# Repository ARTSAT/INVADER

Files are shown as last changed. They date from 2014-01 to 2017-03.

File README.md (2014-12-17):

Hardware / Software design of ARTSAT1:INVADER
========
This repository is for hardware / software design of ARTSAT1:INVADER.  

o satellite/body : contains INVADER's body design and CAD data.  
o satellite/power : contains power OBC's CAD data and source codes.  
o satellite/main : contains main OBC's CAD data and source codes.  
o satellite/mission : contains mission OBC's CAD data and source codes.  
o ground_station/mission : contains some utility software for mission operation.  
o ground_station/utility : contains some utility software such as a viewer or an editor, etc...

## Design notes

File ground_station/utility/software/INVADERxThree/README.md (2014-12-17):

INVADERxThree
=============

A library to handle ARTSAT1:INVADER as the 3D object in Three.js

```html
<script src="three.min.js"></script>
<script src="STLLoader.js"></script>
<script src="invaderxthree.js"></script>

<script>
  ..... // initialization for three.js (renderer, scene, camera, light, etc.)
  
  var invader = new Invader (scene); // INVADER is added to the scene!
  
  ..... // process for the animation
  
</script>
```

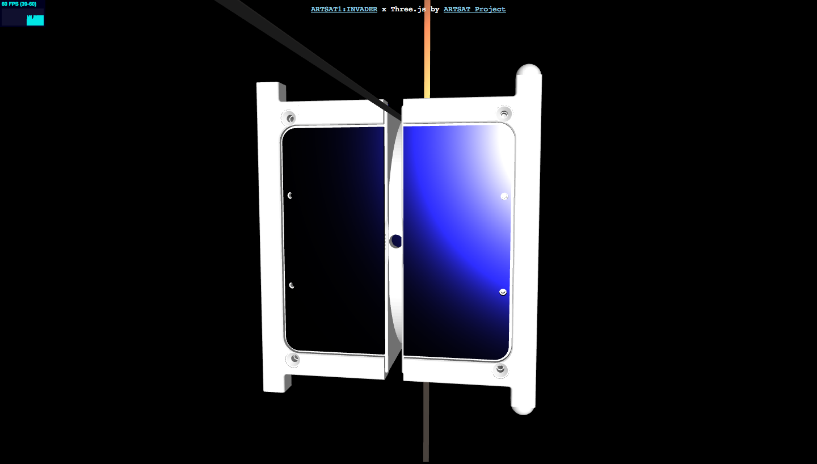
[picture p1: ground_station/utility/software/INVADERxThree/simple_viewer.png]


Demo: http://mokk.net/invaderxthree/examples/spinning.html

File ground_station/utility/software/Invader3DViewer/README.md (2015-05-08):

Invader3DViewer
====
A 3D viewer for INVADER, writted in Javascript.

## Description

[INVADER](http://artsat.jp/en/project/invader), a nano-satellite developed by ARTSAT project, can be viewed on your browser. 
You can zoom in/out and rotate the satellite.

## Demo

http://mokk.net/invader3d/

## Screen shot

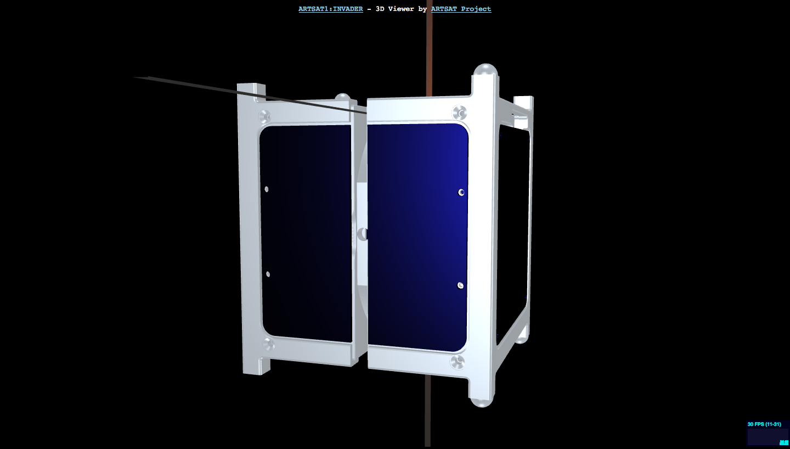
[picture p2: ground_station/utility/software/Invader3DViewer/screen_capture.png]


## Requirement

A browser that supports WebGL (Google Chrome is recommended).

## Licence

This software is released under the MIT License, see LICENSE.txt.

## Author

[Motoki Kimura](https://github.com/motokimura)

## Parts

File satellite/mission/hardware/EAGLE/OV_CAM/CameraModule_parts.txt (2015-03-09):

カメラモジュール部品情報

FFCケーブルの仕様
aitendo  http://www.aitendo.com/page/35

購入品
FFCケーブル(各種)　\480　http://www.aitendo.com/product/7256
　
16極　0.5mmピッチ　全長16cm　逆面導体露出タイプ　を指定

カメラモジュール

OV7670　(刻印がHDF 70-818)
　http://www.aitendo.com/product/2508

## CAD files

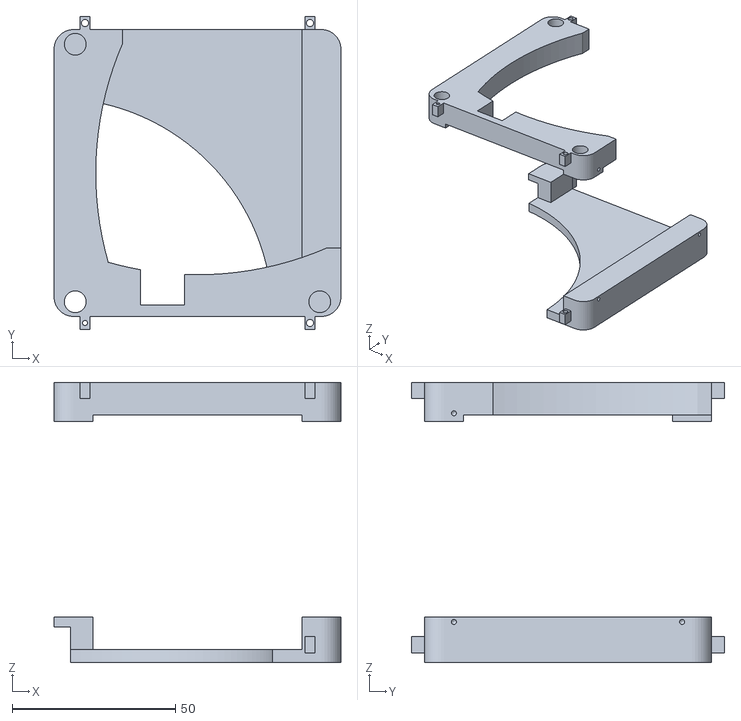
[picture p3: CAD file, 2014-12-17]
ground_station/utility/software/Invader3DViewer/models/invader_weights.stl
88.0 x 96.0 x 86.0

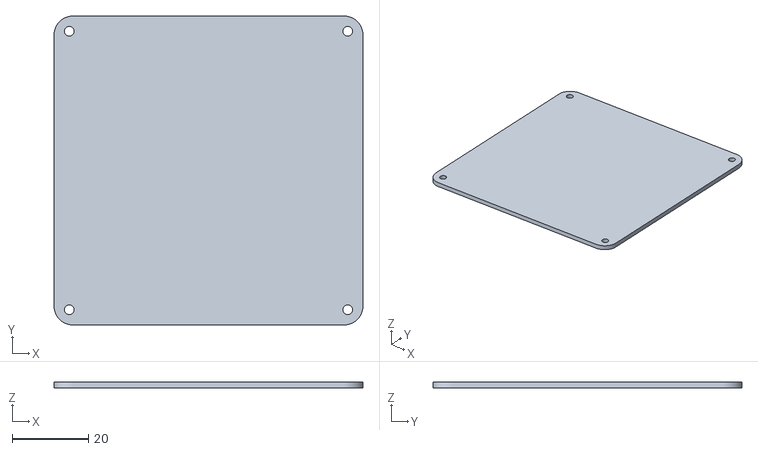
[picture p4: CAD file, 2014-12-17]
ground_station/utility/software/INVADERxThree/models/invader_pannel_mx.stl
81.0 x 81.0 x 1.60

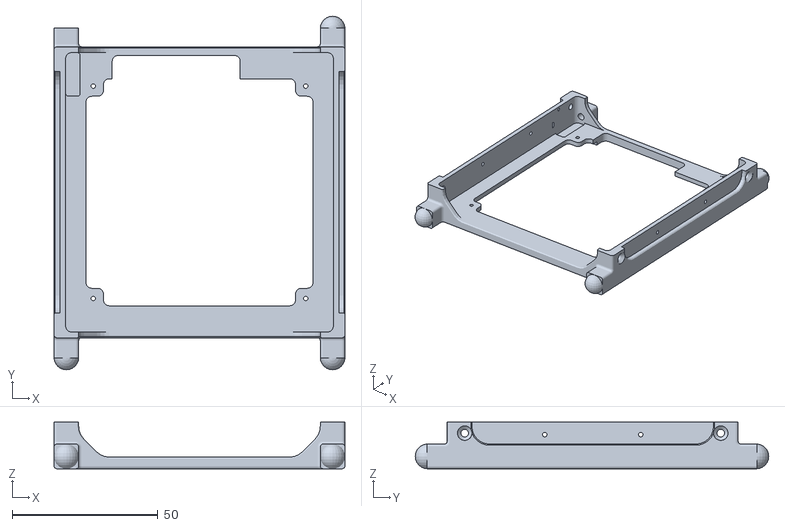
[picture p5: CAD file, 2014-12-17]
satellite/body/hardware/STL/+X.stl
100.0 x 121.5 x 16.0

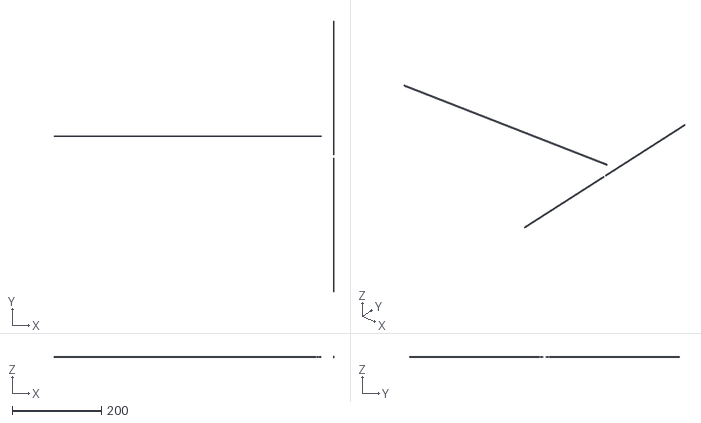
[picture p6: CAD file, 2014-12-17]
ground_station/utility/software/Invader3DViewer/models/invader_antennas.stl
629.0 x 606.8 x 3.00

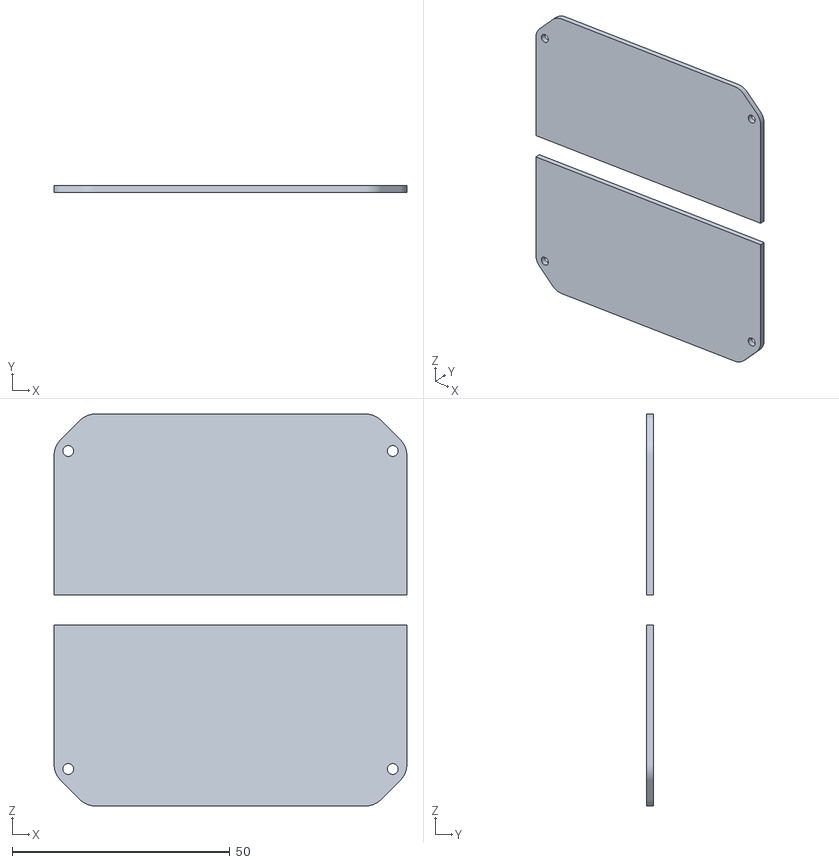
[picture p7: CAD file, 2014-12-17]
ground_station/utility/software/INVADERxThree/models/invader_pannel_mz.stl
81.0 x 1.60 x 90.0

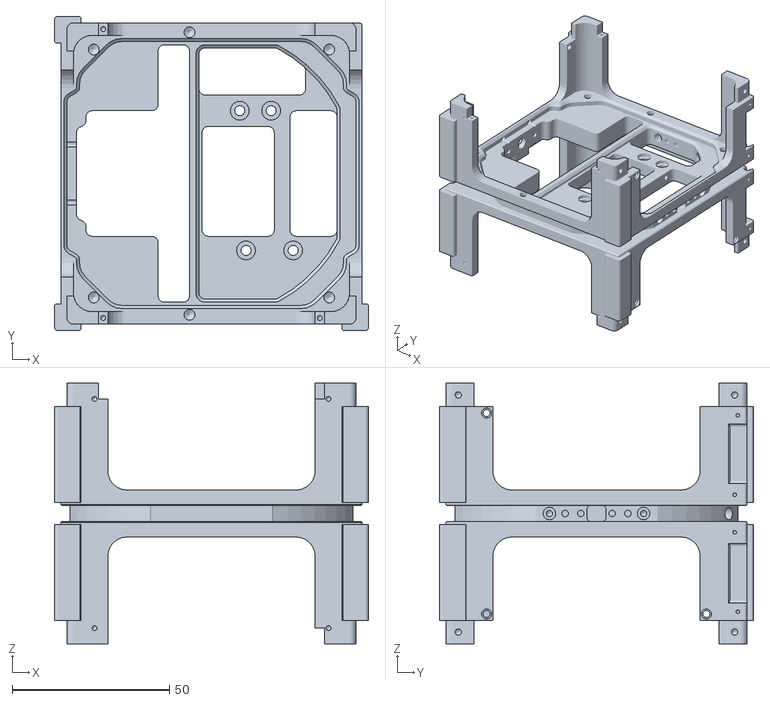
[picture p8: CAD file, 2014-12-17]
satellite/body/hardware/STL/body.stl
100.0 x 100.0 x 83.0

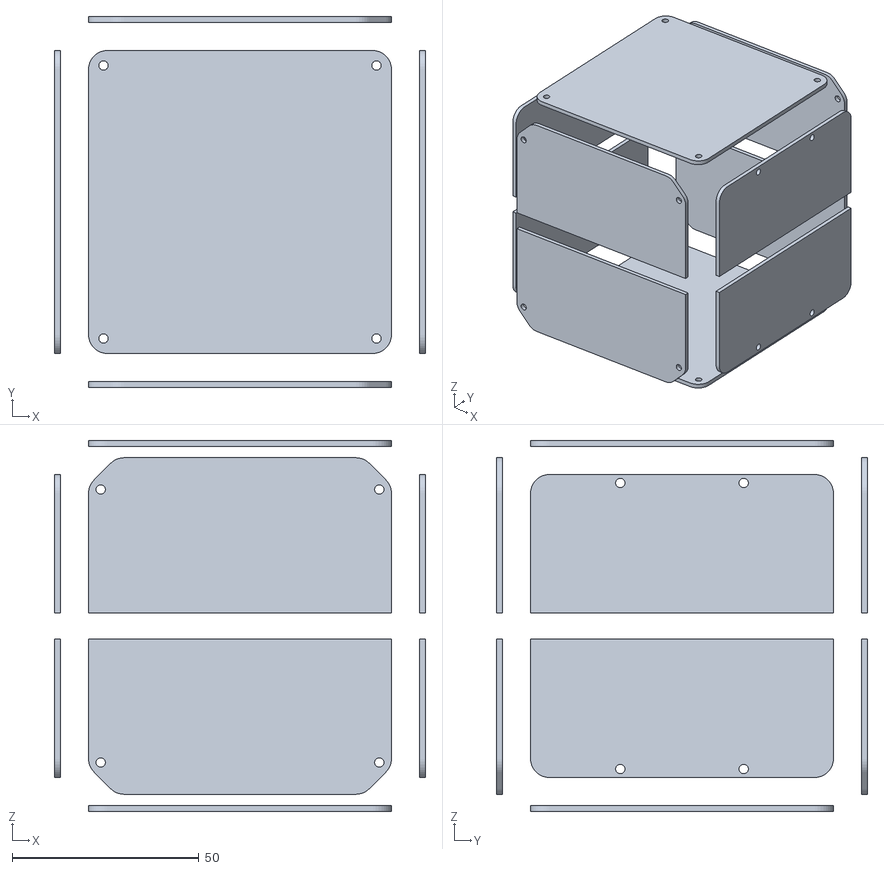
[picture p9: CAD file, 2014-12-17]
ground_station/utility/software/Invader3DViewer/models/invader_pannels.stl
99.2 x 99.2 x 99.2

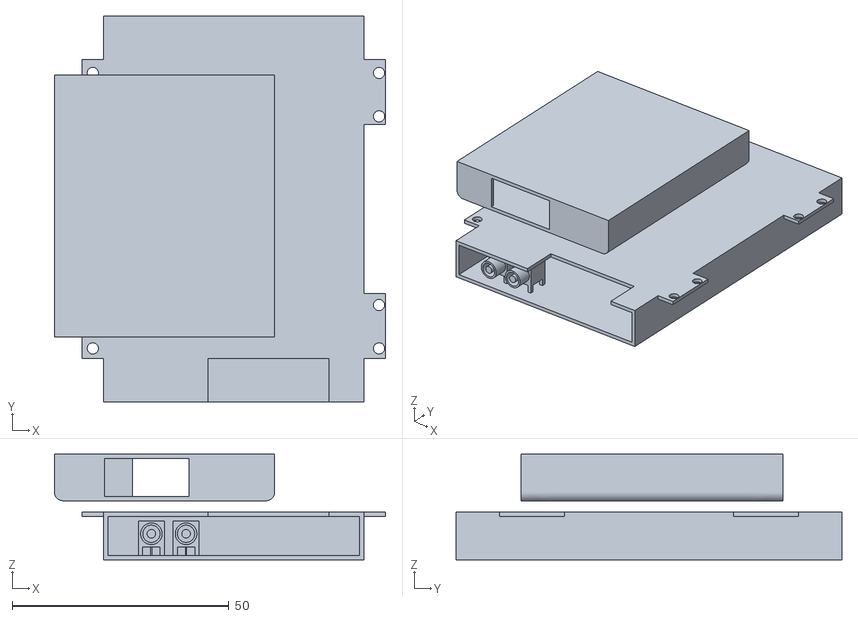
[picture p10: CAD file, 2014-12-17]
ground_station/utility/software/Invader3DViewer/models/invader_telecoms.stl
76.4 x 89.0 x 24.4

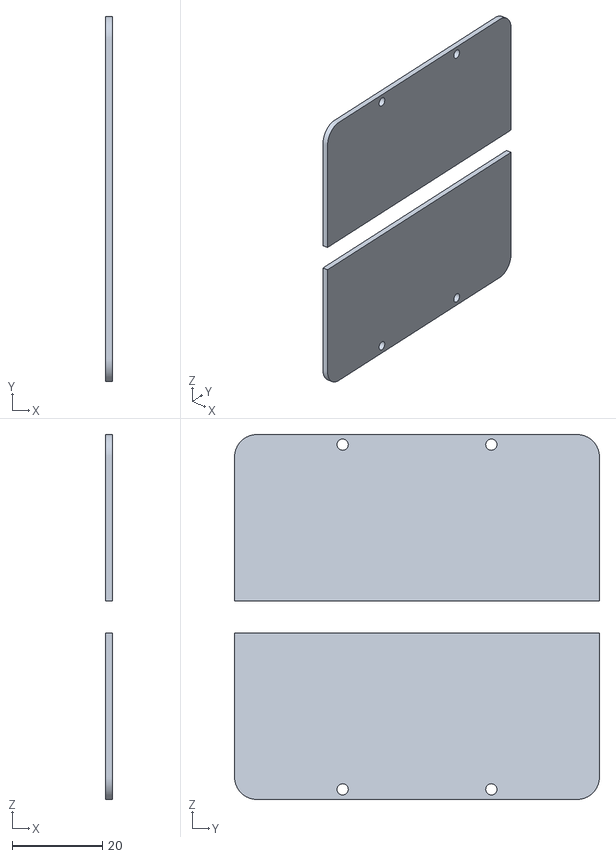
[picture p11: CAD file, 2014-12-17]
ground_station/utility/software/INVADERxThree/models/invader_pannel_my.stl
1.60 x 81.0 x 81.0

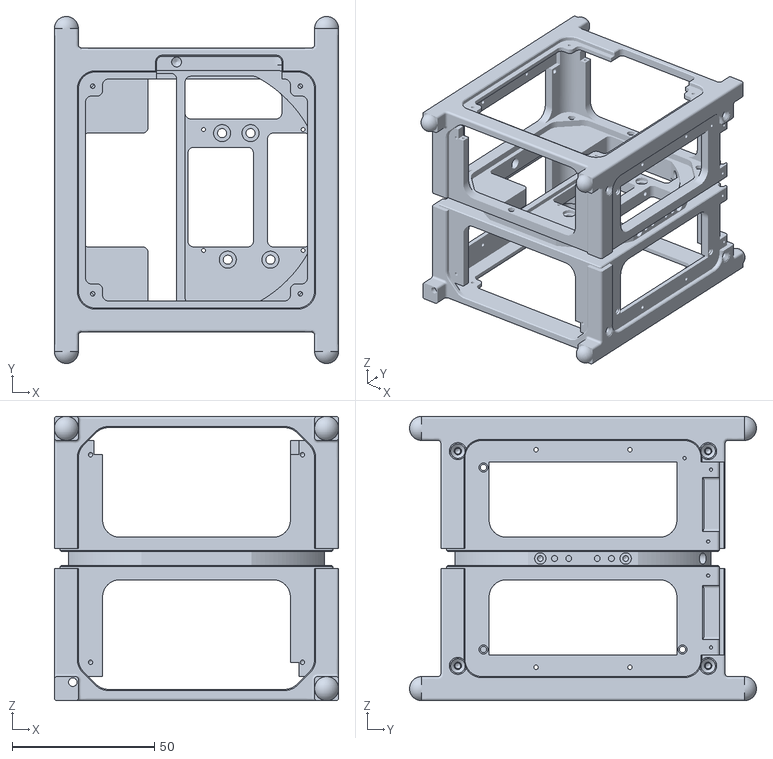
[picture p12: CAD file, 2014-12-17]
ground_station/utility/software/Invader3DViewer/models/invader_frame.stl
100.0 x 122.0 x 100.0

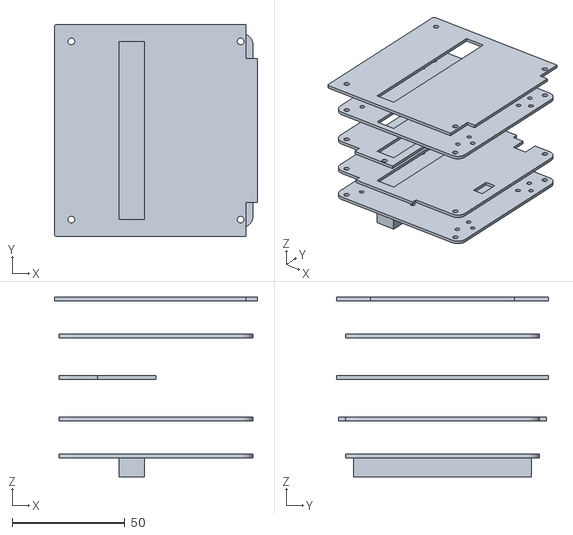
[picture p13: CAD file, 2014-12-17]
ground_station/utility/software/Invader3DViewer/models/invader_boards.stl
90.0 x 94.0 x 79.6

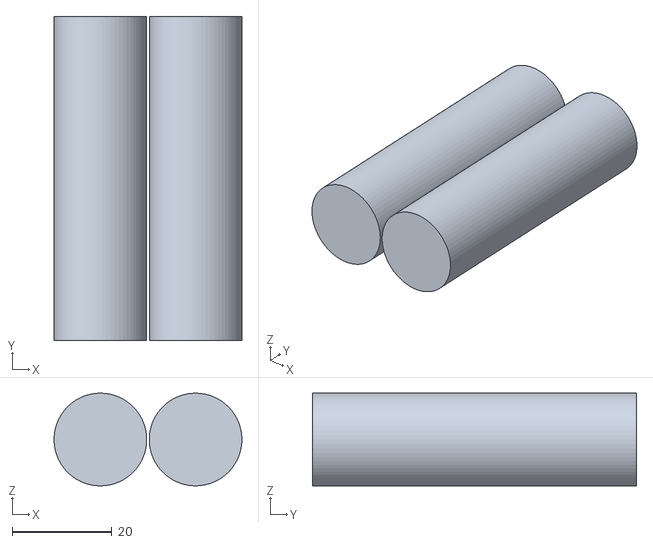
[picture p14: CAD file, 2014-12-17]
ground_station/utility/software/Invader3DViewer/models/invader_batteries.stl
37.7 x 65.0 x 18.6

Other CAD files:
ground_station/utility/software/INVADERxThree/models/invader_pannel_px.stl
ground_station/utility/software/INVADERxThree/models/invader_pannel_pz.stl
ground_station/utility/software/INVADERxThree/models/invader_pannel_py.stl
satellite/body/hardware/Inventor/FM_ver3_1/+X-ver3.12-1.idw
satellite/body/hardware/Inventor/FM_ver3_1/+X-ver3.12.ipt
satellite/body/hardware/Inventor/FM_ver3_1/-X-ver3.12.idw
satellite/body/hardware/Inventor/FM_ver3_1/-X-ver3.12.ipt
satellite/body/hardware/Inventor/FM_ver3_1/body_ver3.17.idw
satellite/body/hardware/Inventor/FM_ver3_1/body_ver3.17.ipt
satellite/body/hardware/STL/-X.stl

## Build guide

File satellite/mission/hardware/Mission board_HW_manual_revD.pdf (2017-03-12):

# ARTSAT Mission board Developer’s Manual

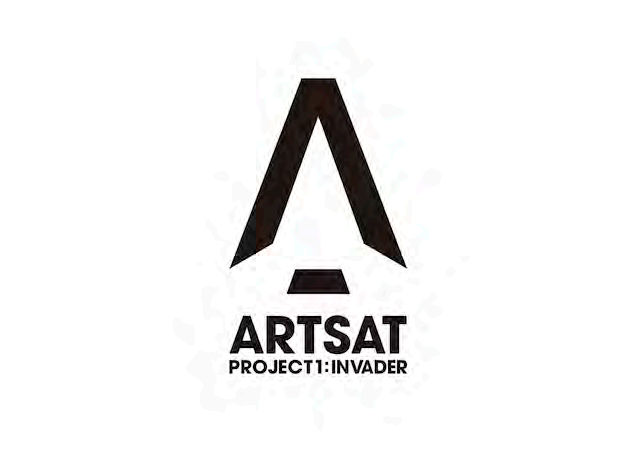
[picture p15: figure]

# Code name: MORIKAWA

# Flight Model

2017/03/12

## Kent Nakazawa (kent_n@outlook.com)

## ・INVADER 衛星(CO-77)の Arduino 互換ミッション機器

## ・Arduino IDE によるアプリケーション開発(MORIKAWA SDK)

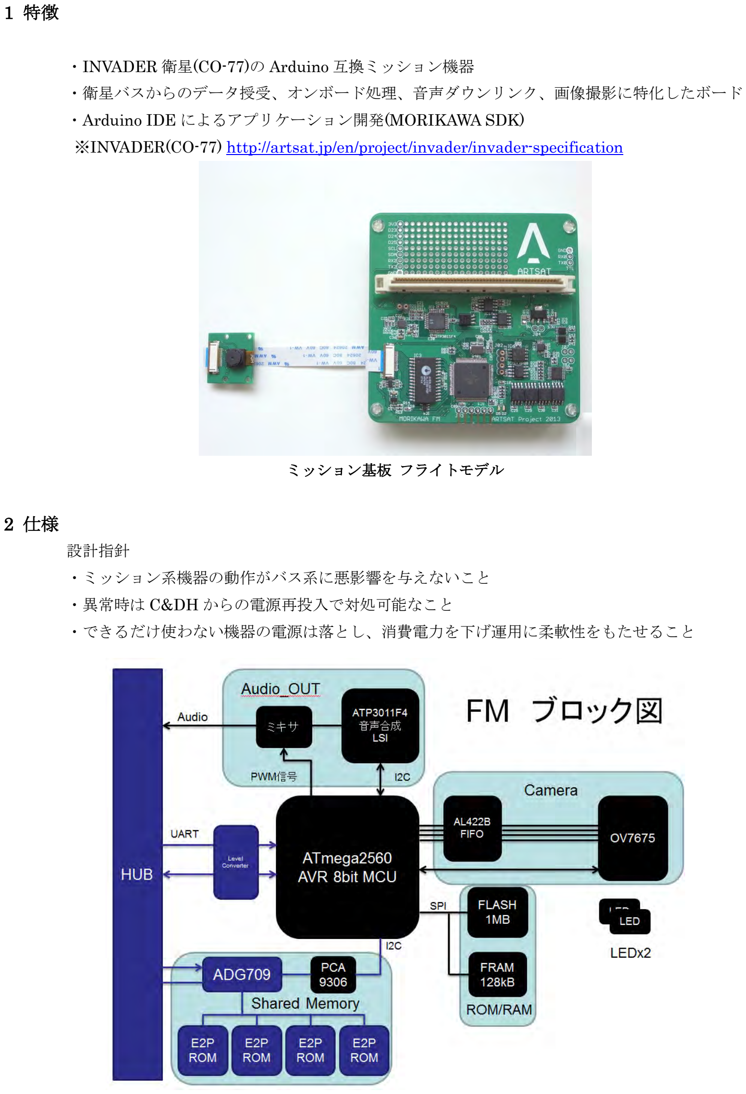
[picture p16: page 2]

1 特徴

・衛星バスからのデータ授受、オンボード処理、音声ダウンリンク、画像撮影に特化したボード

## ※INVADER(CO-77) http://artsat.jp/en/project/invader/invader-specification

ミッション基板 フライトモデル

2 仕様

設計指針
・ミッション系機器の動作がバス系に悪影響を与えないこと
・異常時は C&DH からの電源再投入で対処可能なこと

・できるだけ使わない機器の電源は落とし、消費電力を下げ運用に柔軟性をもたせること

## 2.1 MCU ・ATmega2560(RAM8kB,ROM256kB) 動作周波数 8MHz タイプ

・同期/非同期シリアル I2C_1ch, SPI_1ch,UART_4ch,
2.2 カメラモジュール
・OV7670 CMOS フライトモデルではレンズ一体型モジュールを使用。

## ・AL422B VGA FIFO ・12 / 24MHz クロック発振器 FM は 12MHzOSC

・ピン接続仕様は市販の FIFO 付きカメラモジュールと互換 ・カメラ用素子(モジュール、FIFO)の電源は未使用時に OFF

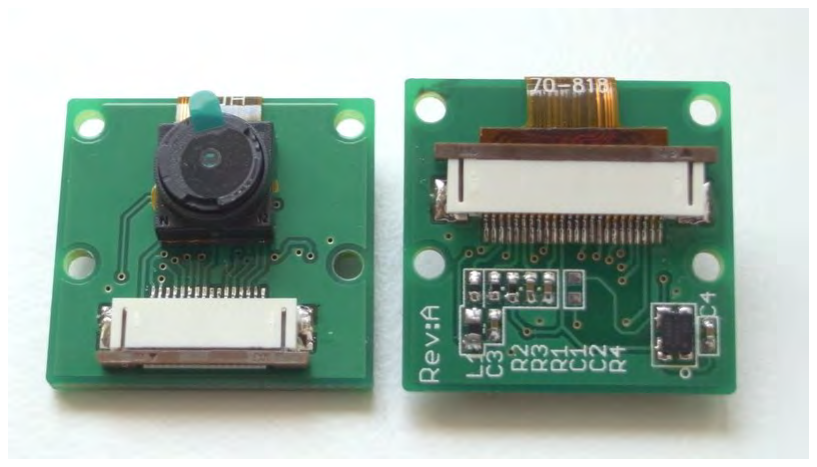
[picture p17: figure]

カメラモジュール 子基板

## 2.3 音声合成 LSI ATP3011F4 日本語音声合成 IC 通信: I2C

## 2.4 不揮発性 RAM ・SPI FRAM 128kB FM25V10

・消費電流が少なく、1 バイト単位でのアクセスが可能な不揮発性メモリ ・M25P80 とピン互換
・Flash や EEPROM へ保存する前のバッファメモリ等
2.5 大容量 ROM ストレージ

## ・SPI Flash メモリ 1MB M25P80

・Flash メモリ。画像、処理結果データの保存先として確保 2.8 共有メモリ

## ・EEPROM(24LC1025) x4 個 電源ドメインは 5V 系

・Main 系が、マルチプレクサ ADG709 によりアクセス権を設定 (LOW=バス系、HIGH=ミッション 系 切り替えラインはプルダウン) し、Mission 側に切り替え権は無い ・基板上のジャンパピンにより単独でアクセス可能 (開発用機能)

バス接続時、フライト時はジャンパピンを外すこと

## 2.6 LED x2 ・ATmega2560 へ接続(正論理)

・主にステータス確認用

2.7 INVADER バス接続用インターフェース

## ・バスは 5V 系 Mission は 3.3V 系

・共有メモリ、バス温度センサは 5V 系、C&DH 電源で動作 ・2 電源バスバッファにより電圧変換(UART、共有メモリ I2C)

3 開発環境

3.1 ソフトウェア開発環境

機器一覧

## ・USB-Serial 変換器/プログラマ https://www.sparkfun.com/products/9873

・リセット(DTR)がついた TTL レベル UART 接続 5V 供給できるもの

## ・PC/Mac/Linux ・既製品の Arduino ボード（ArduinoISP として使用）

・Arduino IDE(1.0.6) ※最新の IDE ではボード定義の追加が難しいため、1.0.6 での構築を推奨

## https://www.arduino.cc/en/Main/OldSoftwareReleases#previous

## 3.2 Arduino IDE 設定 (ArduinoIDE バージョン 1.0.6)

・Arduino IDE をインストールする
・MorikawaSDK に必要なファイルをダウンロードする。

## https://github.com/ARTSAT/MorikawaSDK をダウンロードし、 Arduino ディレクトリ内の二つのディレクトリ（libraries, hardware）を ArduinoIDE のスケッチ保存フォルダ（デフォルトでは documents/Arduino 内）に

入れる。
・ArduinoIDE を立ち上げ、ツール/board からボード選択リストを開き、

## Mega Pro 2560V 3.3V を選択

3.3 AVR ブートローダ設定

## ATmega2560 8MHz 版ブートローダの設定

・MORIKAWA にシリアルブートローダーを設定することで、シリアルポートからスケッチをアップロ

ードできる
・書き込みは ICSP という方式で、Arduino ボードをライターとして使用する手法を使う ・ICSP 用 4 ピン端子(J02 )を J02 に設けており、Arduino ISP 等で書き込みが可能

書き込みの流れは以下のサイトを参考にする

## https://www.arduino.cc/en/Tutorial/ArduinoISP Morikawa での各種端子の位置は、ピンアサイン表（MISSION_board_HW_layout.pdf）を参照

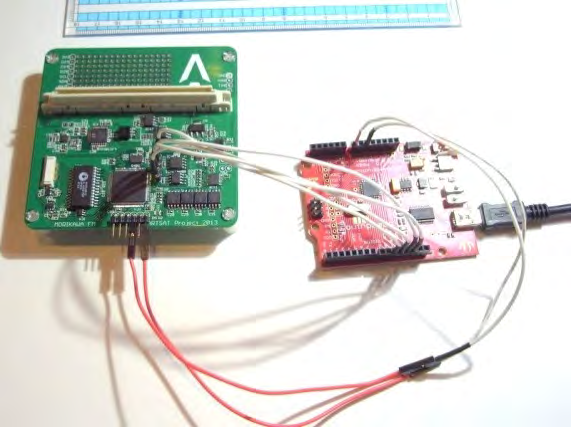
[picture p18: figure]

Arduino ISP によるブートローダーの書き込み

簡易手順
・まず、ライター用の Arduino ボードの設定で、スケッチ例から ArduinoISP を選択し、書き込む ・次に、ターゲットとなるボードの設定（mega-pro-3.3V）を選択する
・ライター用ボードの SPI 端子、リセット端子を、MORIKAWA ボードの J02 端子に接続する ・MORIKAWA への電源投入を行う。（5V 程度）
・IDE のツール/書き込み装置 にて、Arduino as ISP が選択されているか確認する ・ツール/ブートローダーを書き込む をクリックし、書き込みを行う

（結線や設定が間違っている場合、エラーが発生する）

## 3.4 Morikawa Software 書き込み、動作確認 Arduino IDE の設定 ボード設定: mega pro 2560V 3.3V

ポート：接続した USB シリアルポートの COM 番号

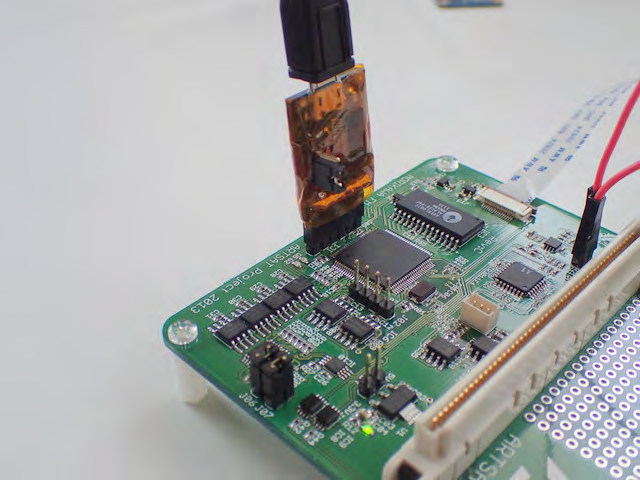
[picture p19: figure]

USB シリアル変換器の接続
・ファイル/スケッチの例から、MorikawaSDK を選択する。

・動作確認する場合は、

## DebugTest(ボードの動作確認)

HelloSpace(デジトーカーと音声のテスト)

を選択し、書き込んで単体で動作を確認できる
音声出力は、ジャンパ線をモノラルのオーディオジャックに接続すれば、ヘッドホンやスピ ーカーに直接繋いで確認できる。

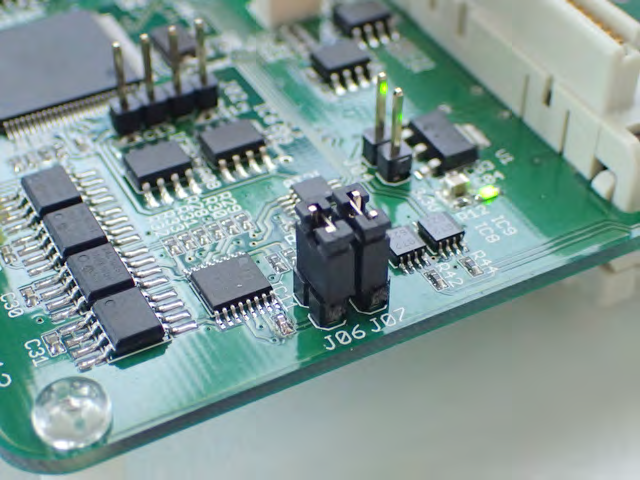
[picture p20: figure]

単体での動作確認の際は、I2C の共有メモリ部のジャンパピンを二つとも図のように接続する。

3.5 連携開発時の注意

・Invader 衛星に組み込んだ後は、USB シリアル変換器から電源を入力しないよう 6 ピン端子から電 源ピンを除去する。MORIKAWA の電源は Invader のシステムから投入
・ICSP 書き込みは 5V 系のボードからでも OK ・念のためその日の最初の電源投入前に、電源ライン（J04）がショートしていないか調べる ・I2C 機器をテストする場合、ボード単体では 2 つのジャンパピンをショートさせる必要がある （単体でオープン状態だと、音声合成 IC と共有メモリにアクセスできない） 逆に、Main と接続したり、連系試験を行う場合は、ジャンパピンを必ず取り除くこと

4 電気特性

・消費電流

## case1, 5V 系なし、周辺機器設定なし、UART 115k で 100ms ごとに送信: 9mA case2, カメラ系 ON 時: 約 60mA (数秒間)

5 設計情報

## Power Domain

基板上の回路は 3 つの電源ドメインから構成される

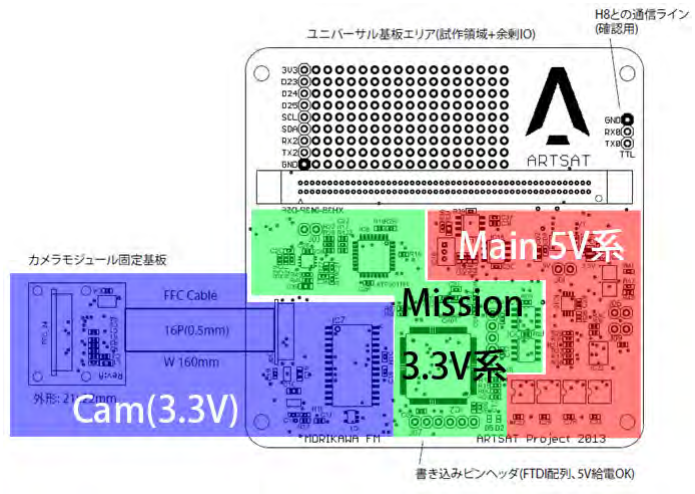
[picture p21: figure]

5V 系は Main 基板の延長となり、Main の電力(5V)をもらい常時通電している。
ミッションは 3.3V 系であり、Main の指令で、衛星の電源系により電源投入される

カメラ系はアプリによって、ミッション系から電源投入される。消費電力を下げるため、撮影終了とともにカメ ラモジュールの内部クロックを下限値まで落とし、FIFO の読み出し時の電力削減を行っている

※ユニバーサルエリアは試作部品追加が可能なように設けた すぐそばに電源ライン、AVR の UART 1ch,I2C バス、デジタル I/Ox3 を引き出した シルク印刷のピン番号は ArduinoAPI のピン番号となっている

## (参照 MISSION_FM_HW_layout)

FM 品の修正)

フライトモデルについて、搭載前の基板への変更点
・カメラ回路: VSYNC と WRST が繋がっていない 解決策: MCU 端子をハンダブリッジ(35,36 番ピン) ・回路修正: リセットライン ATMEGA2560 と ATP3011F4 間の接続を分離(パターンカット) ・回路修正: C01、R07、R43 は未実装
・回路図中の LED の極性が逆（そのまま実装すると光らない）

5 資料

## Artsat GitHub https://github.com/ARTSAT/MorikawaSDK

6 設計データリビジョン

・フライトモデル: Rev:A (基板上での修正)
・2015/03/24 | Rev:C (リワーク内容の反映、部品削除、部品定数の変更) Rev:A とソフトウェア互換あり
・2017 March | Rev:D (LED の極性の反映、書き込み手順の追加)

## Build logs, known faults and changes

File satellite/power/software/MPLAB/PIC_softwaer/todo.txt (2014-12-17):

プログラム改修
・CW間隔をコマンドで変更できるようにする
・CWの周波数を修正
・CWの間隔はあけてないかも知れない！！＜要確認
・前
・今、ヒータは動かないようにしている（閾値で）

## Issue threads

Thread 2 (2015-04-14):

ArtSat Project on STEMN

DaveRevay2, 2015-04-14:
Hey ArtSat team,

I've been collecting together a database of awesome satellite projects and posting them on [STEMN](https://stemn.com/fields/cubesat).

I've added your ArtSat projects already:
https://stemn.com/projects/invader-artsat-1
https://stemn.com/projects/despatch-artsat-2

It'd be really great if you could join the STEMN community. I'll transfer the project ownership over to you if you do. STEMN allows you to blog about your projects, contact other teams and ask questions in space related forums.

We’re currently in closed beta but you can sign up using the following link:
https://stemn.com/?org=J05312734
Once you’ve made an account, or if you have any questions, send me a email at david@stemn.com and I can transfer the project to your account.

Thanks, David

hemokosa, 2015-04-14:
Dear David,

Hello! Thank you very much for checking our ARTSAT project.
We are very glad that you added our two spacecrafts on your site.

I have signed in to  STEMN now. I will check it and mail you again.

Thanks again and keep in touch.

All the best,

Akihiro Kubota
Project Leader, ARTSAT Project

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

DaveRevay2, 2015-04-15:
Thanks for your quick reply Akihiro,

I'm very excited to have you on the platform. Now that I have transferred the project over to you, you can invite any other team members.
https://stemn.com/threads/%5Bhow-to%5D-how-do-i-add-new-team-members-to-my-project.

Should I invite you to the DESPATCH project also?

Kind regards and thanks, David

hemokosa, 2015-04-15:
Dear David,

Thanks. Please invite me to the DESPATCH project, too!

All the best,

Akihiro Kubota

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

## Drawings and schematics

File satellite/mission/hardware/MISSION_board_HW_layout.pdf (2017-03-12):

## MORIKAWA (FM) HardWare Pin Map 2017/03/12

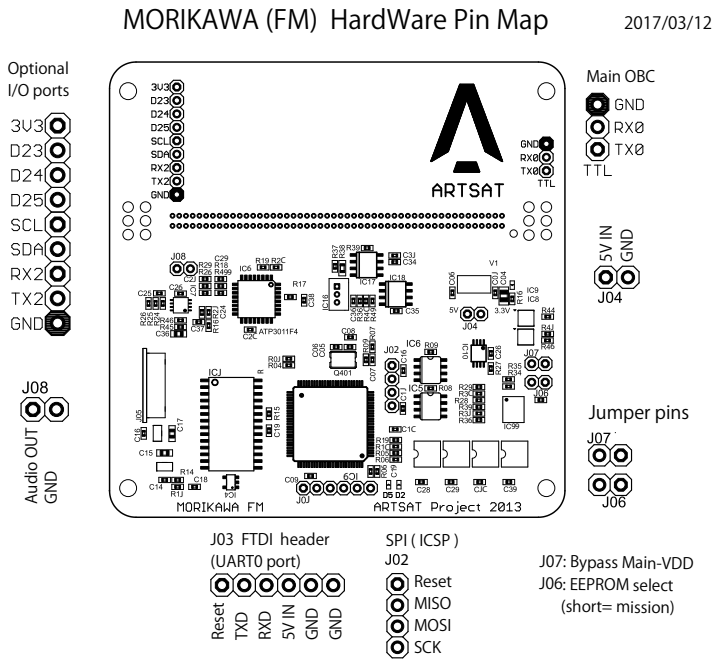
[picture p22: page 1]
Reset MISO MOSI SCK; Main OBC; Audio OUT; GND; Reset; TXD; RXD; J06: EEPROM select (short= mission); J03 FTDI header (UART0 port); Optional I/O ports; SPI ( ICSP )

Jumper pins ⁵V IN GND

J07: Bypass Main-VDD

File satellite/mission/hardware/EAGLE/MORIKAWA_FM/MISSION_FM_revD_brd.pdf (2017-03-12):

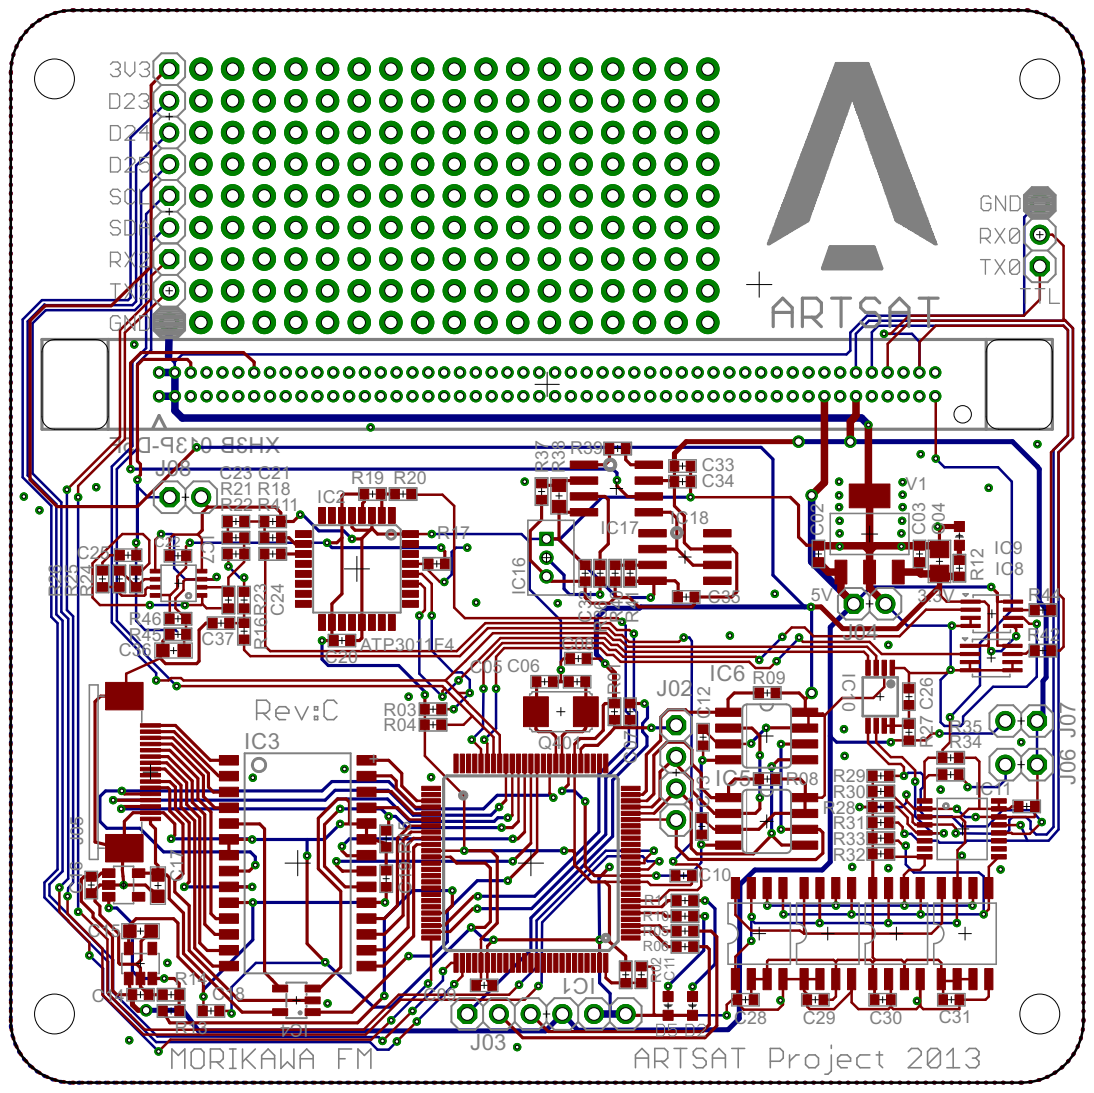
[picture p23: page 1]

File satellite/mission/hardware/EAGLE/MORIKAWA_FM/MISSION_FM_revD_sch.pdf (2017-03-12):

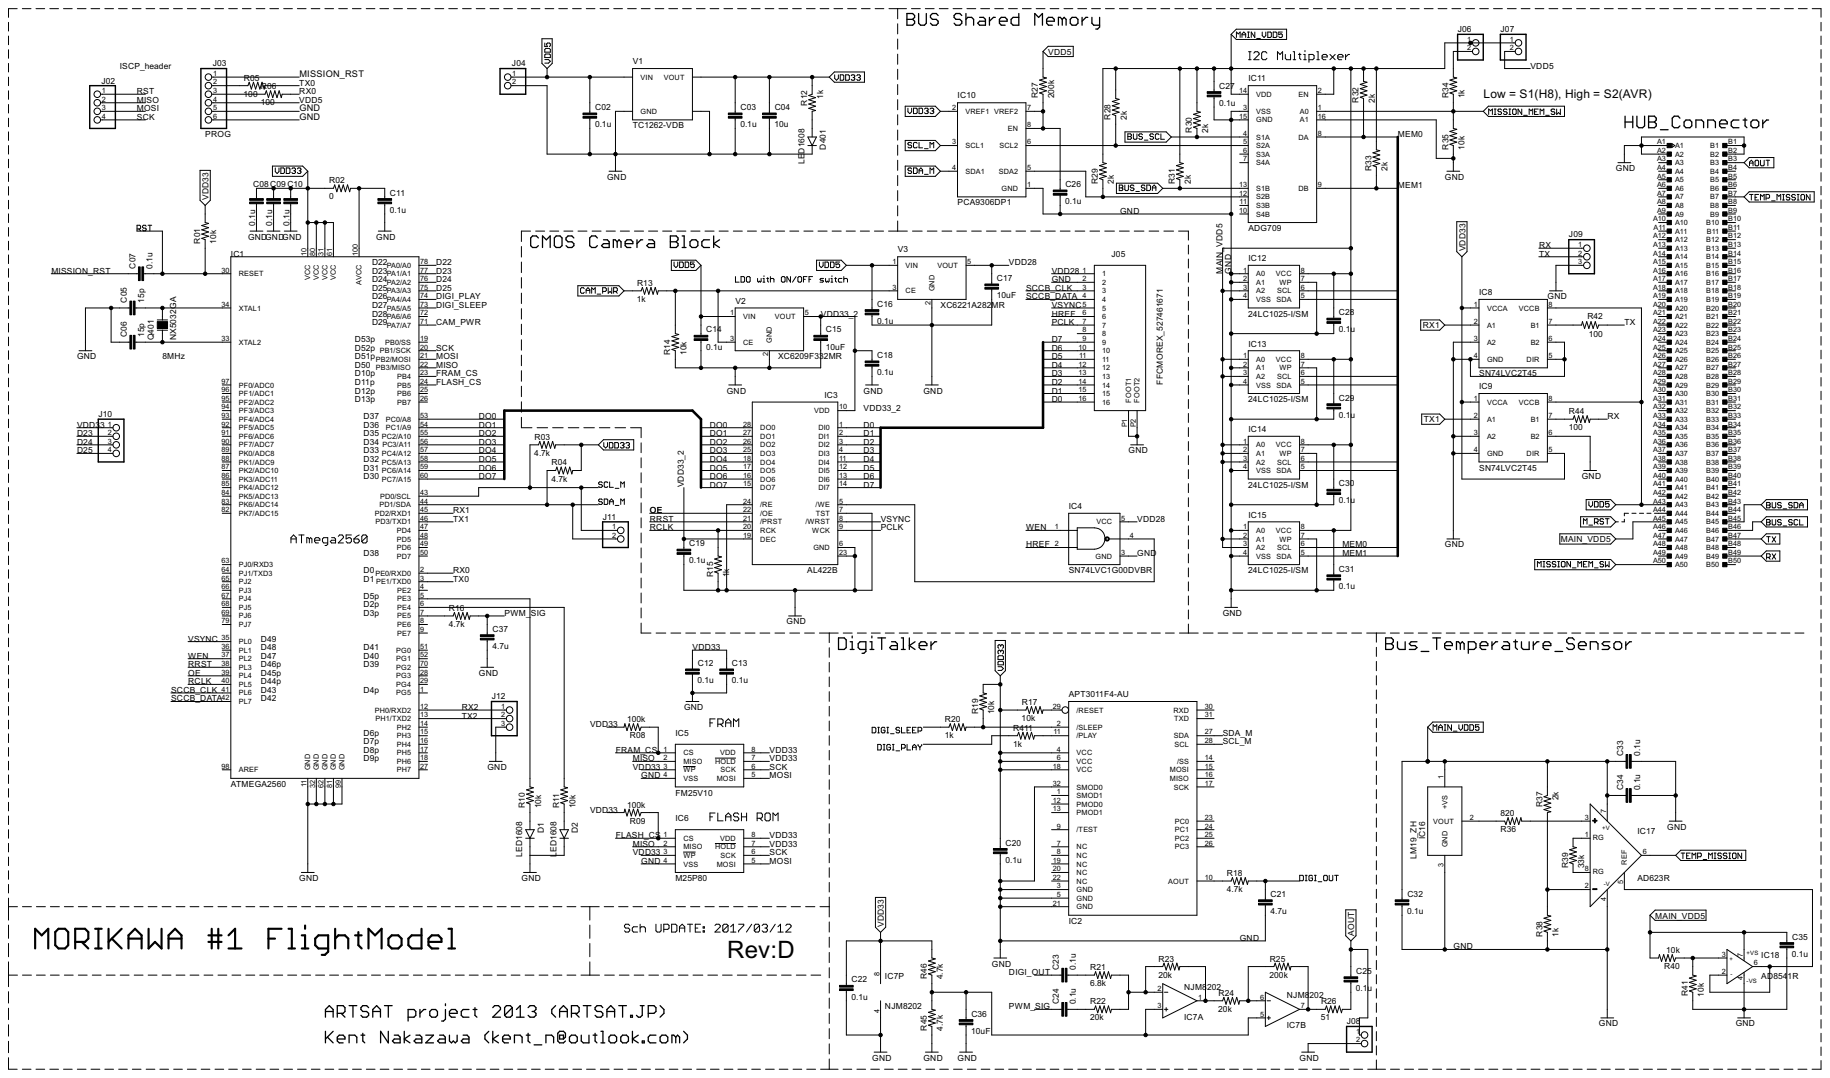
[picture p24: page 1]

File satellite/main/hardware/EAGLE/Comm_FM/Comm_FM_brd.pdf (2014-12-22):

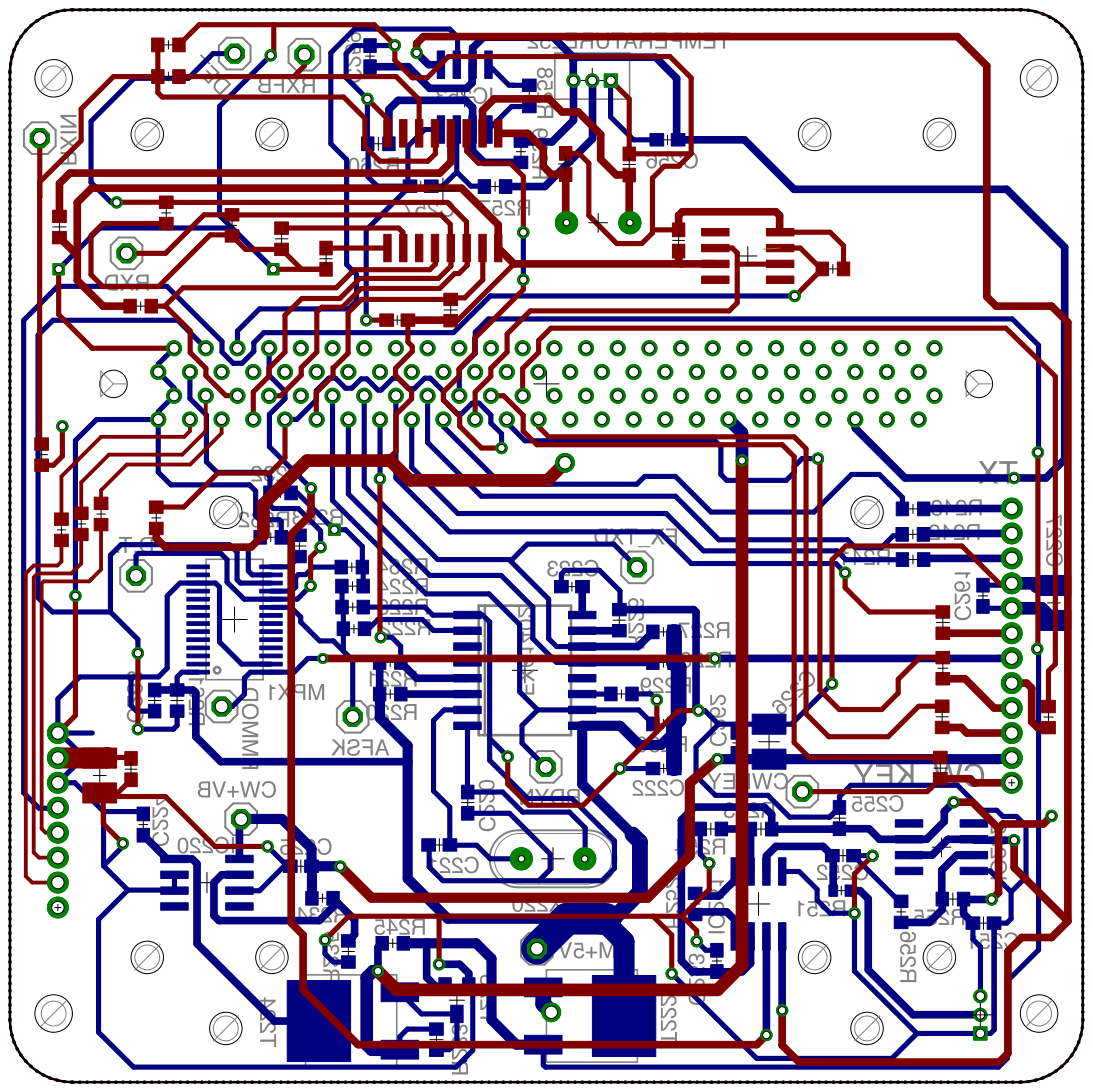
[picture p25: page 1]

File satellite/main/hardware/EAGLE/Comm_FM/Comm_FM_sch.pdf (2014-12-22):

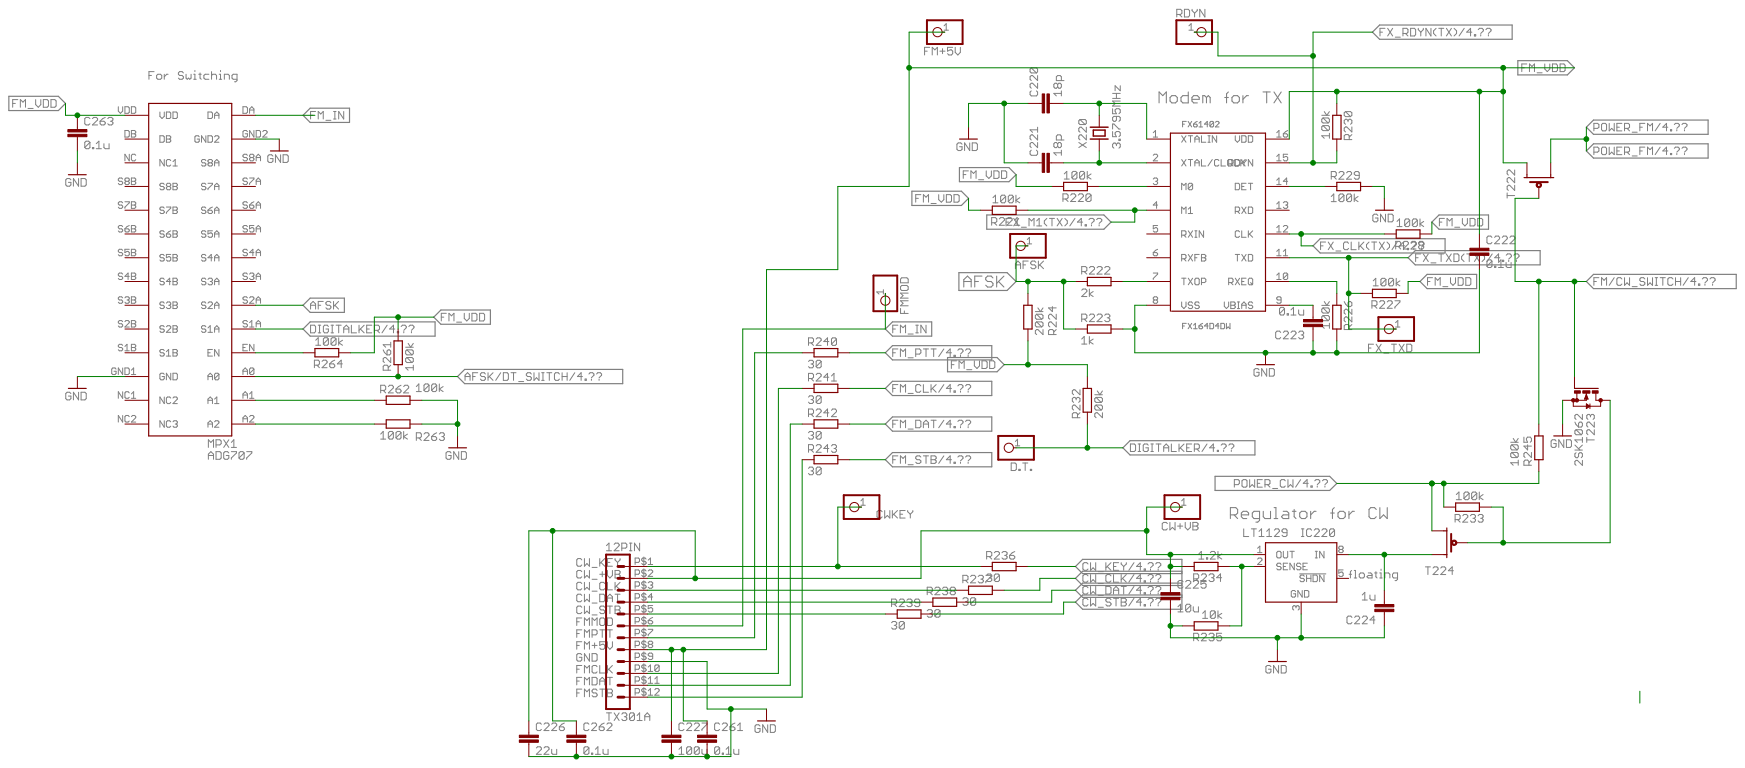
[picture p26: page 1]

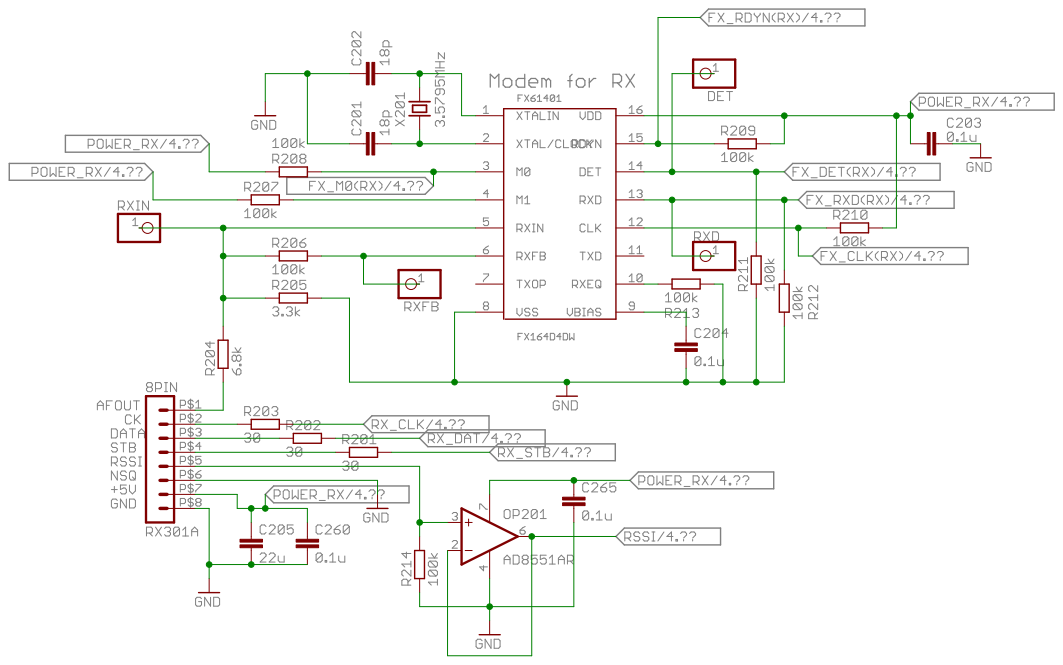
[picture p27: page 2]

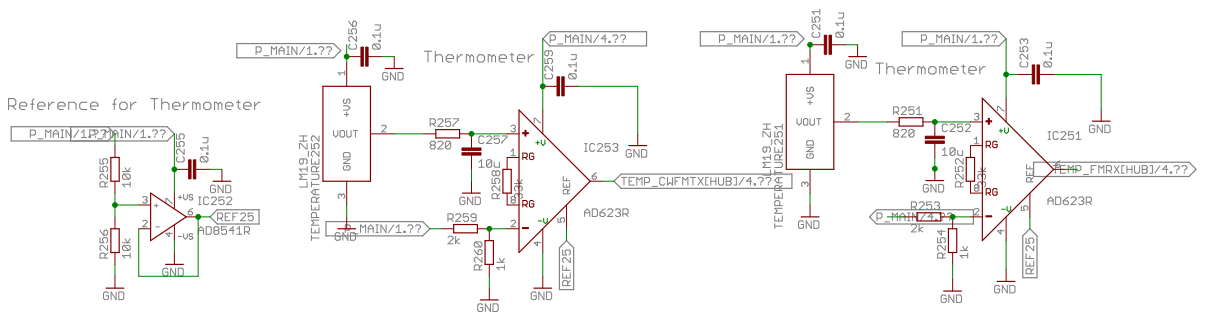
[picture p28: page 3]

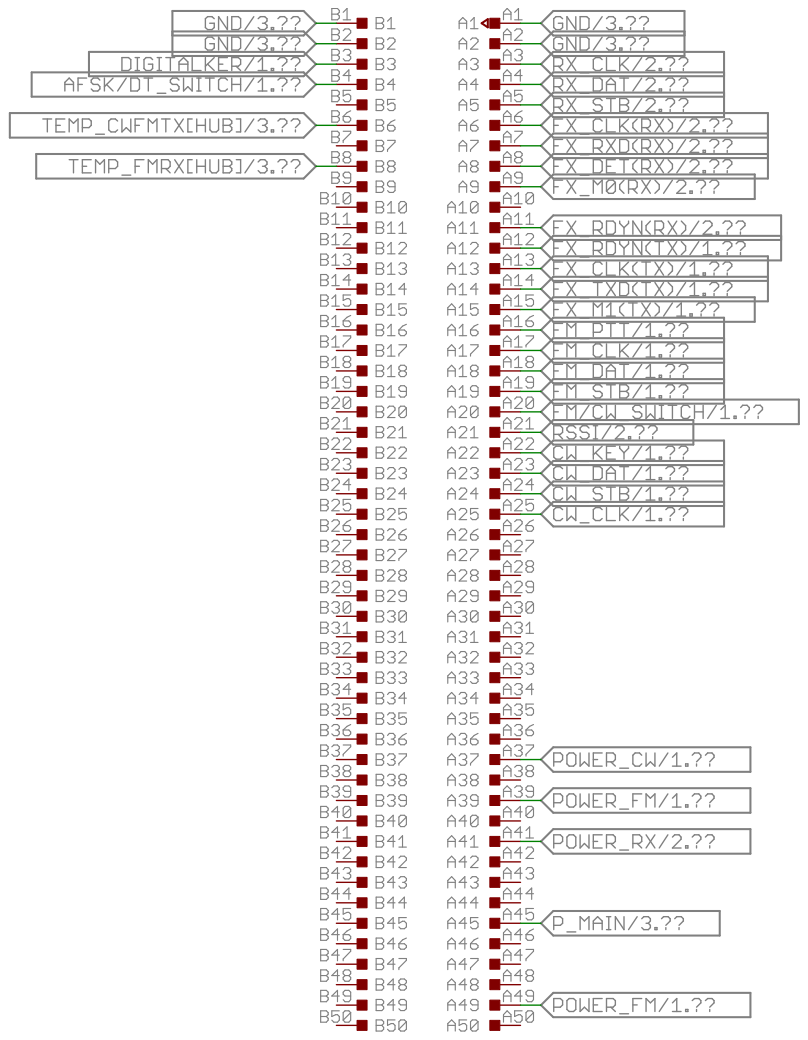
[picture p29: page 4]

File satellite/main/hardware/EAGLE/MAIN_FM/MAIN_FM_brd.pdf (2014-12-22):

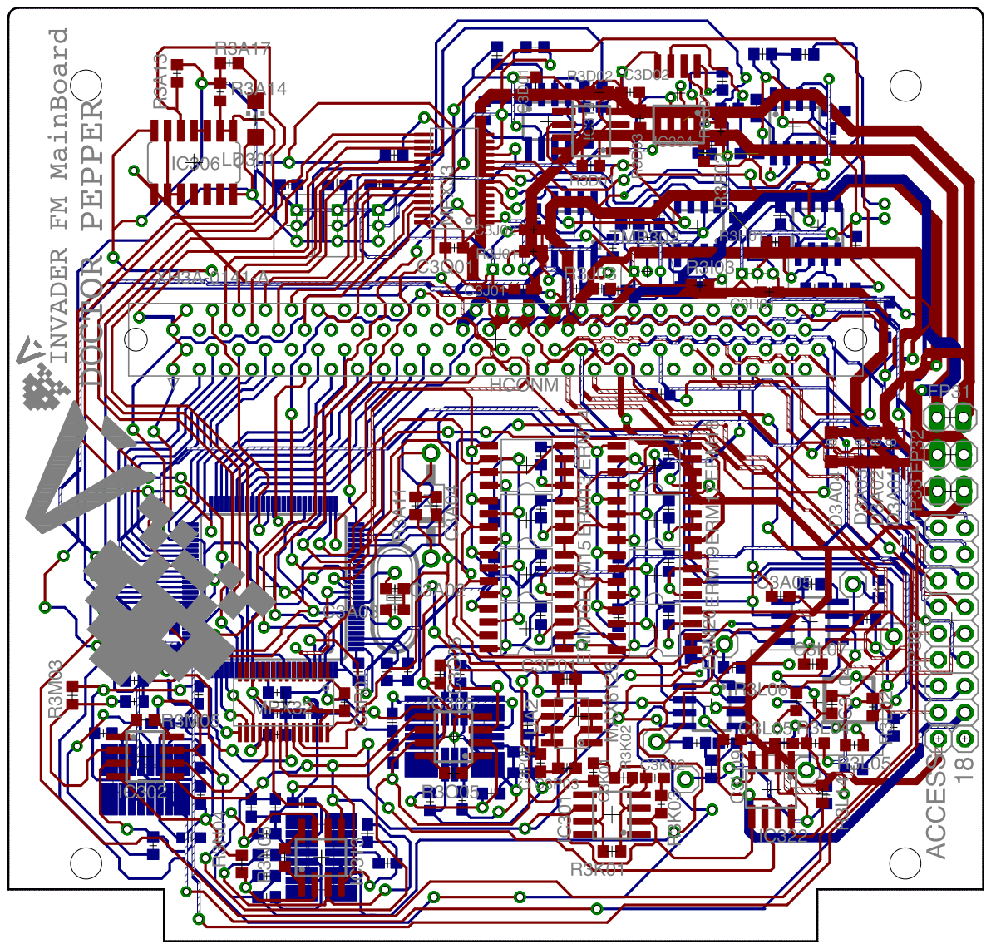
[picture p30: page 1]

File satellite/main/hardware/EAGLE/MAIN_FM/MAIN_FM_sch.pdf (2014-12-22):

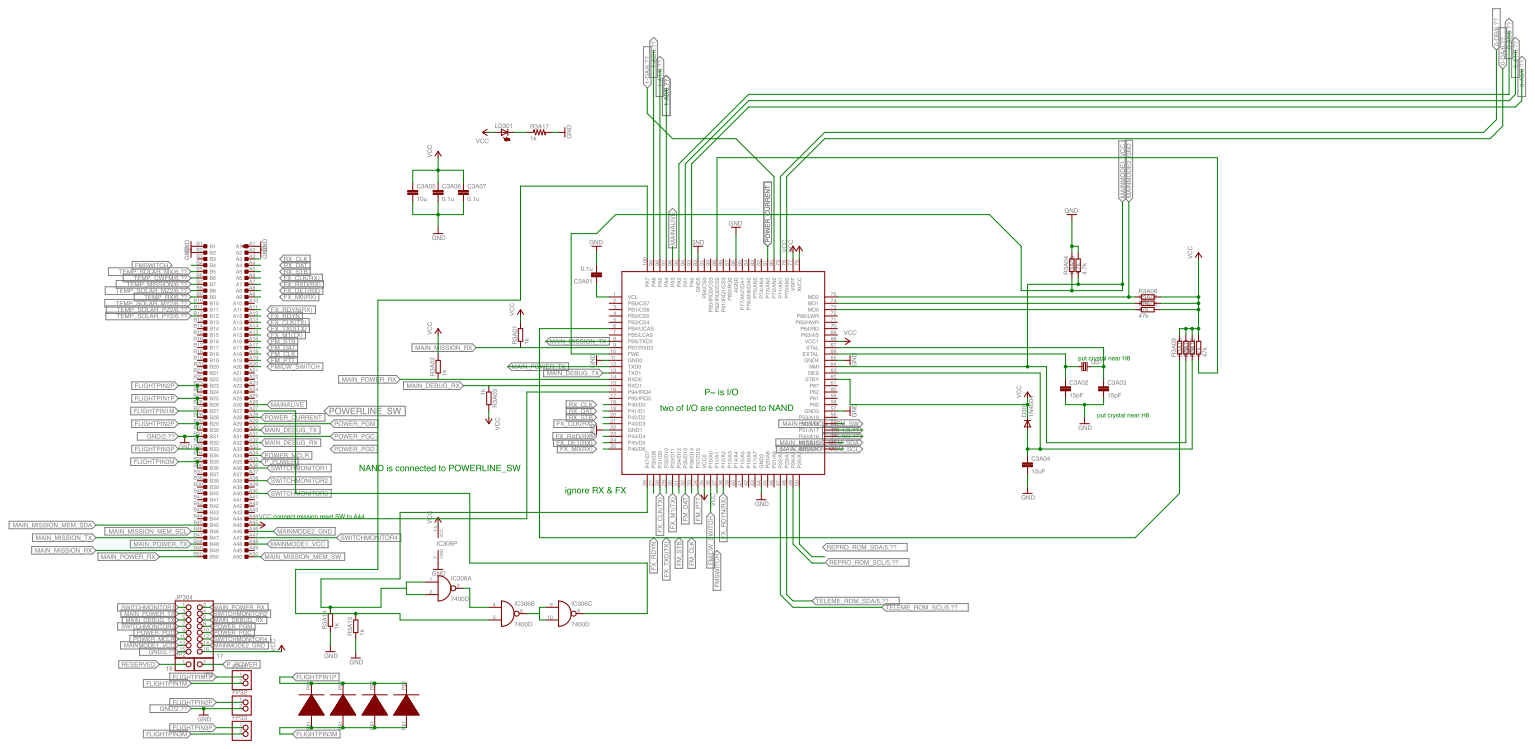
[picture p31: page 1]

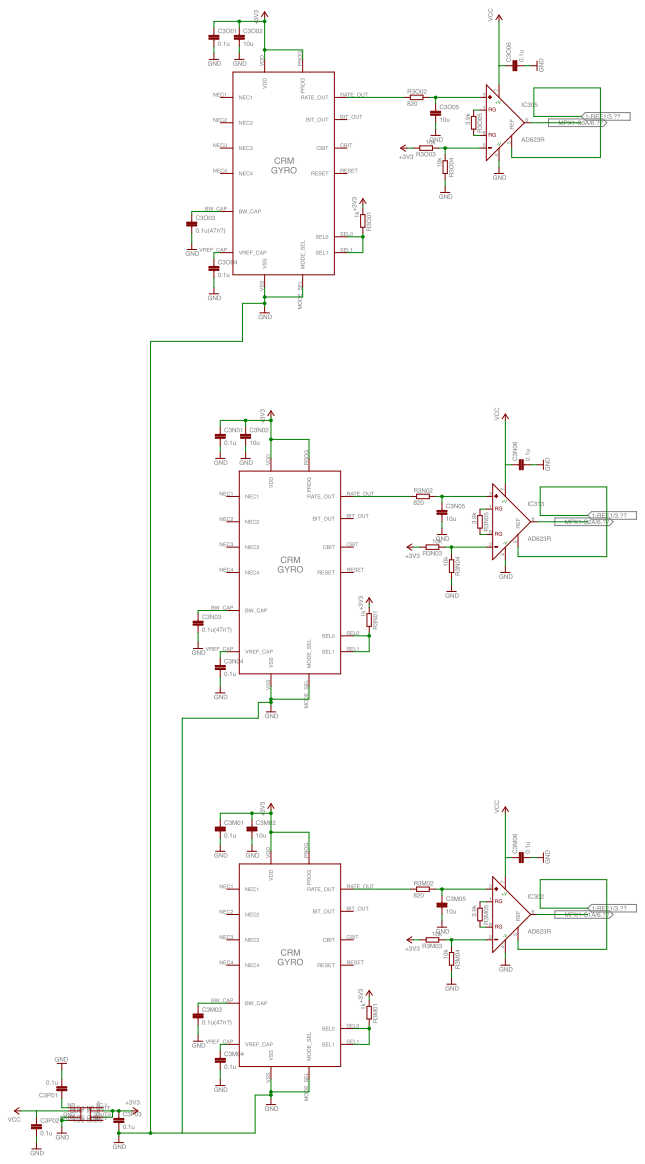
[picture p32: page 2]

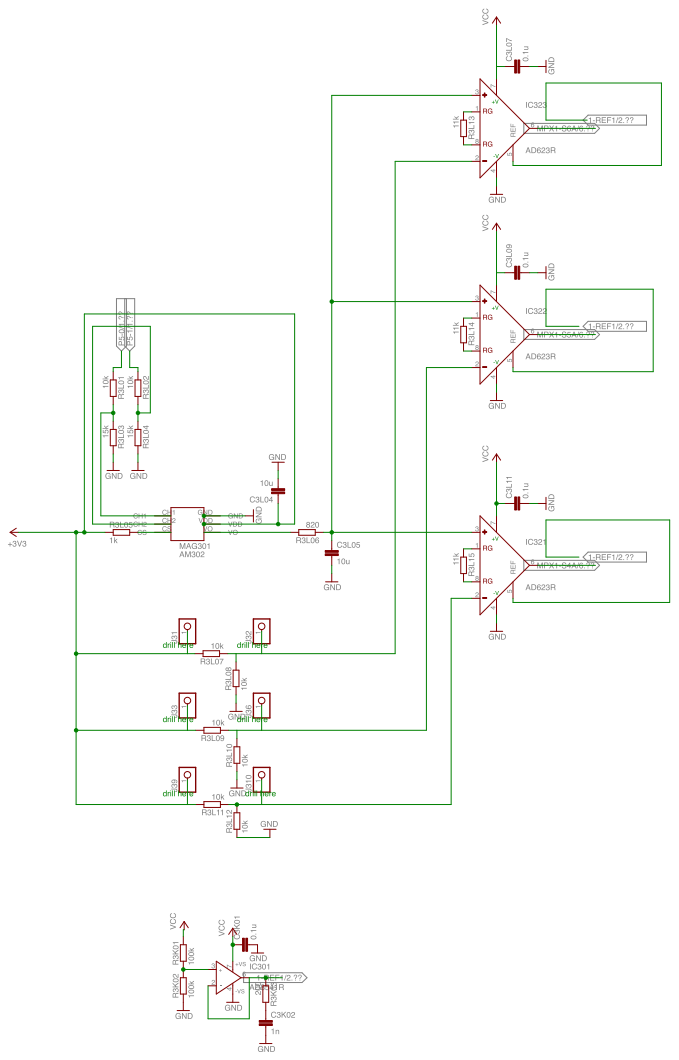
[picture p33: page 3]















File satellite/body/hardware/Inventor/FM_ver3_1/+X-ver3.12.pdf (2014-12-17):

D | D

1.95 0

+X-ver3.12-1

toshiki | 2013/07/22

A ( 4 : 1 )
D | D

+X-ver3.12-1

toshiki | 2013/07/22

B


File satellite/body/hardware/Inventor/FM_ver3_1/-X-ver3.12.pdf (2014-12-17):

11

22


A ( 4 : 1 )

D | D

-X-ver3.12

toshiki | 2013/07/23

D

(


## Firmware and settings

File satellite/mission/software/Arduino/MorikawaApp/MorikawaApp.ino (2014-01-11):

/*
**      ARTSAT Morikawa Application
**
**      Original Copyright (C) 2013 - 2014 HORIGUCHI Junshi.
**                                          http://iridium.jp/
**                                          zap00365@nifty.com
**      Portions Copyright (C) <year> <author>
**                                          <website>
**                                          <e-mail>
**      All rights reserved.
**
**      Version     Arduino
**      Website     http://artsat.jp/
**      E-mail      info@artsat.jp
**
**      This source code is for Arduino IDE.
**      Arduino 1.0.5
**
**      MorikawaApp.ino
**
**      ------------------------------------------------------------------------
**
**      GNU GENERAL PUBLIC LICENSE (GPLv3)
**
**      This program is free software: you can redistribute it and/or modify
**      it under the terms of the GNU General Public License as published by
**      the Free Software Foundation, either version 3 of the License,
**      or (at your option) any later version.
**      This program is distributed in the hope that it will be useful,
**      but WITHOUT ANY WARRANTY; without even the implied warranty of
**      MERCHANTABILITY or FITNESS FOR A PARTICULAR PURPOSE.
**      See the GNU General Public License for more details.
**      You should have received a copy of the GNU General Public License
**      along with this program. If not, see <http://www.gnu.org/licenses/>.
**
**      このプログラムはフリーソフトウェアです。あなたはこれをフリーソフトウェア財団によって発行された
**      GNU 一般公衆利用許諾書（バージョン 3 か、それ以降のバージョンのうちどれか）が定める条件の下で
**      再頒布または改変することができます。このプログラムは有用であることを願って頒布されますが、
**      *全くの無保証* です。商業可能性の保証や特定目的への適合性は、言外に示されたものも含め全く存在しません。
**      詳しくは GNU 一般公衆利用許諾書をご覧ください。
**      あなたはこのプログラムと共に GNU 一般公衆利用許諾書のコピーを一部受け取っているはずです。
**      もし受け取っていなければ <http://www.gnu.org/licenses/> をご覧ください。
*/

#include <MorikawaSDK.h>

//#define TARGET_BUILD_DEBUG

#define REGISTER_APP(param)\
    g_setup = &param##_setup;\
    g_loop = &param##_loop;

enum {
    APP_SELF_TEST               = 0,
    APP_HELLO_SPACE,
    APP_SPEECH_TEXT,
    APP_CODE_TEXT,
    APP_PLAY_MELODY,
    APP_INVADER_BOT,
    APP_INVADER_MUSIC,
    APP_INVADER_CAM,
    APP_INVADER_VM,
    APP_TELEMETRY_DUMP,
    MGR_ERASE_SELFTESTLOG       = 128,
    MGR_FORMAT_EEPROM,
    MGR_FORMAT_SHAREDMEMORY,
    MGR_FORMAT_FRAM,
    MGR_FORMAT_FLASHROM,
    APP_LIMIT
};

static void dump(TSTError error, int hint);

static void(*g_setup)(void)(NULL);
static void(*g_loop)(void)(NULL);
static TSTError g_error(TSTERROR_OK);

void setup(void)
{
    TSTError error;
    
#ifdef TARGET_BUILD_DEBUG
    Serial.begin(9600);
#endif
    error = __debug__(Morikawa.setup(), 0);
    if (error == TSTERROR_OK) {
#ifdef TARGET_BUILD_DEBUG
        SharedMemory_setup();
        SharedMemory_loop();
#endif
        switch (Morikawa.getBootMode()) {
            case APP_HELLO_SPACE:
                REGISTER_APP(HelloSpace)
                break;
            case APP_SPEECH_TEXT:
                REGISTER_APP(SpeechText)
                break;
            case APP_CODE_TEXT:
                REGISTER_APP(CodeText)
                break;
            case APP_PLAY_MELODY:
                REGISTER_APP(PlayMelody)
                break;
            case APP_INVADER_BOT:
                REGISTER_APP(InvaderBot)
                break;
            case APP_INVADER_MUSIC:
                REGISTER_APP(InvaderMusic)
                break;
            case APP_INVADER_CAM:
                REGISTER_APP(InvaderCam)
                break;
            case APP_INVADER_VM:
                REGISTER_APP(InvaderVM)
                break;
            case APP_TELEMETRY_DUMP:
                REGISTER_APP(TelemetryDump)
                break;
            case MGR_ERASE_SELFTESTLOG:
                REGISTER_APP(EraseSelfTestLog)
                break;
            case MGR_FORMAT_EEPROM:
                REGISTER_APP(FormatEEPROM)
                break;
            case MGR_FORMAT_SHAREDMEMORY:
                REGISTER_APP(FormatSharedMemory)
                break;
            case MGR_FORMAT_FRAM:
                REGISTER_APP(FormatFRAM)
                break;
            case MGR_FORMAT_FLASHROM:
                REGISTER_APP(FormatFlashROM)
                break;
            case APP_SELF_TEST:
            default:
                REGISTER_APP(SelfTest)
                break;
        }
        (*g_setup)();
    }
    else {
        Morikawa.shutdown();
    }
    return;
}

void loop(void)
{
    Morikawa.loop();
    (*g_loop)();
    return;
}

void delay10mTimes(unsigned int times)
{
    for (; times > 0; --times) {
        delay(10);
        Morikawa.loop();
    }
    return;
}

TSTError __debug__(TSTError error, int hint)
{
    if (error != TSTERROR_OK) {
        if (g_error == TSTERROR_OK) {
            dump(error, hint);
            g_error = error;
        }
    }
    return error;
}

static void dump(TSTError error, int hint)
{
    static char s_text[16];
    
    snprintf(s_text, sizeof(s_text), "SOS E%02x H%03d", error, hint);
#ifdef TARGET_BUILD_DEBUG
    Serial.println(s_text);
#endif
    Morikawa.setText(TEXT_DEBUG, s_text);
    Morikawa.playMorse(NOTE_C6, s_text);
    return;
}

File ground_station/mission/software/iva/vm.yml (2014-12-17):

code_size: 127

registers:
  - ERRN
  - FUNC
  - RETV
  - HCUR
  - HEAP
  - ARG0
  - ARG1
  - ARG2
  - ARG3
  - ARG4
  - ARG5
  - ARG6
  - ARG7
  - ARG8
  - ARG9
  - ARGA

instructions:
  - [ END             ]
  - [ NOP             ]
  - [ SET,    R, L    ]
  - [ SETC,   R, C    ]
  - [ SETI,   R, I    ]
  - [ CLR,    R       ]
  - [ MOV,    R, R    ]
  - [ XCHG,   R, R    ]
  - [ CALL            ]
  - [ JMP,    O       ]
  - [ JMPIF,  R, O    ]
  - [ JMPNOT, R, O    ]
  - [ INC,    R       ]
  - [ DEC,    R       ]
  - [ NEG,    R       ]
  - [ ADD,    R, R    ]
  - [ SUB,    R, R    ]
  - [ MUL,    R, R    ]
  - [ DIV,    R, R, R ] 
  - [ AND,    R, R    ]
  - [ OR,     R, R    ]
  - [ XOR,    R, R    ]
  - [ NOT,    R       ]
  - [ SHR,    R, R    ]
  - [ SHL,    R, R    ]
  - [ EQ,     R, R, R ] 
  - [ LT,     R, R, R ]
  - [ LE,     R, R, R ]
  - [ GT,     R, R, R ]
  - [ GE,     R, R, R ]
  - [ WAIT,   R       ] 
  - [ TXT,    L, V    ]
  - [ EXC,    L       ]
  - [ COMPRESSED      ]

constants:
  -
    - CAMERA_RAW_VGA
    - CAMERA_RAW_QVGA
    - CAMERA_RAW_QCIF
    - CAMERA_RGB565_QVGA
    - CAMERA_RGB565_QQVGA
    - CAMERA_RGB565_QQCIF
    - CAMERA_YUV422_QVGA
    - CAMERA_YUV422_QQVGA
    - CAMERA_YUV422_QQCIF
  -
    - TSTERROR_OK
    - TSTERROR_FAILED
    - TSTERROR_NO_SUPPORT
    - TSTERROR_NO_MEMORY
    - TSTERROR_BAD_MEMORY
    - TSTERROR_USED_MEMORY
    - TSTERROR_INVALID_PARAM
    - TSTERROR_INVALID_STATE
    - TSTERROR_INVALID_FORMAT
    - TSTERROR_INVALID_STORAGE
    - TSTERROR_INVALID_IMPLEMENT
    - TSTERROR_ABNORMAL_SHUTDOWN
  -
    - CURRENT_BATTERY
    - CURRENT_SOLAR
    - CURRENT_SOLAR_PX
    - CURRENT_SOLAR_MX
    - CURRENT_SOLAR_PY1
    - CURRENT_SOLAR_MY1
    - CURRENT_SOLAR_PY2
    - CURRENT_SOLAR_MY2
    - CURRENT_SOLAR_PZ
    - CURRENT_SOLAR_MZ
    - CURRENT_POWERCPU
    - CURRENT_MAINCPU
    - CURRENT_MISSIONCPU
    - CURRENT_ANTENNA
    - CURRENT_BATTERYHEATER
    - CURRENT_TX
    - CURRENT_CW
    - CURRENT_RX
  - 
    - TEMPERATURE_BATTERY1
    - TEMPERATURE_BATTERY2
    - TEMPERATURE_BATTERY3
    - TEMPERATURE_SOLAR_PX
    - TEMPERATURE_SOLAR_MX
    - TEMPERATURE_SOLAR_PY1
    - TEMPERATURE_SOLAR_MY1
    - TEMPERATURE_SOLAR_PY2
    - TEMPERATURE_SOLAR_MY2
    - TEMPERATURE_SOLAR_PZ1
    - TEMPERATURE_SOLAR_MZ1
    - TEMPERATURE_SOLAR_PZ2
    - TEMPERATURE_SOLAR_MZ2
    - TEMPERATURE_POWERCPU
    - TEMPERATURE_MAINCPU
    - TEMPERATURE_MISSIONCPU
    - TEMPERATURE_CWTX
    - TEMPERATURE_RX
  -
    - GYRO_X
    - GYRO_Y
    - GYRO_Z
  -
    - MAGNET_X
    - MAGNET_Y
    - MAGNET_Z
  -
    - TEXT_X
    - TEXT_Y
    - TEXT_Z
    - TEXT_DEBUG
  -
    FREQUENCY_END: -1
    FREQUENCY_REST: 0
  -
    NOTE_END: -1
    NOTE_REST: 0
    NOTE_B0:  31
    NOTE_C1:  33
    NOTE_CS1: 35
    NOTE_D1:  37
    NOTE_DS1: 39
    NOTE_E1:  41
    NOTE_F1:  44
    NOTE_FS1: 46
    NOTE_G1:  49
    NOTE_GS1: 52
    NOTE_A1:  55
    NOTE_AS1: 58
    NOTE_B1:  62
    NOTE_C2:  65
    NOTE_CS2: 69
    NOTE_D2:  73
    NOTE_DS2: 78
    NOTE_E2:  82
    NOTE_F2:  87
    NOTE_FS2: 93
    NOTE_G2:  98
    NOTE_GS2: 104
    NOTE_A2:  110
    NOTE_AS2: 117
    NOTE_B2:  123
    NOTE_C3:  131
    NOTE_CS3: 139
    NOTE_D3:  147
    NOTE_DS3: 156
    NOTE_E3:  165
    NOTE_F3:  175
    NOTE_FS3: 185
    NOTE_G3:  196
    NOTE_GS3: 208
    NOTE_A3:  220
    NOTE_AS3: 233
    NOTE_B3:  247
    NOTE_C4:  262
    NOTE_CS4: 277
    NOTE_D4:  294
    NOTE_DS4: 311
    NOTE_E4:  330
    NOTE_F4:  349
    NOTE_FS4: 370
    NOTE_G4:  392
    NOTE_GS4: 415
    NOTE_A4:  440
    NOTE_AS4: 466
    NOTE_B4:  494
    NOTE_C5:  523
    NOTE_CS5: 554
    NOTE_D5:  587
    NOTE_DS5: 622
    NOTE_E5:  659
    NOTE_F5:  698
    NOTE_FS5: 740
    NOTE_G5:  784
    NOTE_GS5: 831
    NOTE_A5:  880
    NOTE_AS5: 932
    NOTE_B5:  988
    NOTE_C6:  1047
    NOTE_CS6: 1109
    NOTE_D6:  1175
    NOTE_DS6: 1245
    NOTE_E6:  1319
    NOTE_F6:  1397
    NOTE_FS6: 1480
    NOTE_G6:  1568
    NOTE_GS6: 1661
    NOTE_A6:  1760
    NOTE_AS6: 1865
    NOTE_B6:  1976
    NOTE_C7:  2093
    NOTE_CS7: 2217
    NOTE_D7:  2349
    NOTE_DS7: 2489
    NOTE_E7:  2637
    NOTE_F7:  2794
    NOTE_FS7: 2960
    NOTE_G7:  3136
    NOTE_GS7: 3322
    NOTE_A7:  3520
    NOTE_AS7: 3729
    NOTE_B7:  3951
    NOTE_C8:  4186
    NOTE_CS8: 4435
    NOTE_D8:  4699
    NOTE_DS8: 4978
  - 
    DURATION_01: 1
    DURATION_02: 2
    DURATION_04: 4
    DURATION_08: 8
    DURATION_16: 16
    DURATION_32: 32
  -
    - QUALIFIER_NONE
    - QUALIFIER_DOT
    - QUALIFIER_DOTDOT
    - QUALIFIER_TRIPLE
    - QUALIFIER_QUINTUPLE
    - QUALIFIER_SEXTUPLE
    - QUALIFIER_SEPTUPLE
    - QUALIFIER_NONUPLE
  -
    PIN_FRAM_CS:          10
    PIN_FLASHROM_CS:      11
    PIN_LED_X:            5
    PIN_LED_Y:            2
    PIN_TONE_WAVE:        3
    PIN_DIGITALKER_PLAY:  26
    PIN_DIGITALKER_SLEEP: 27
    PIN_CAMERA_POWER:     29
    PIN_CAMERA_VSYNC:     49
    PIN_CAMERA_HREF:      48
    PIN_CAMERA_WEN:       47
    PIN_CAMERA_RRST:      46
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

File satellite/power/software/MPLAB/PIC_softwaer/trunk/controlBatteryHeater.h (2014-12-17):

#define BATTERYONTEMP (int16_t)185
//バッテリーヒーターオンの閾値
//29度(100)
//ヒーター常にオフ(255)
#define BATTERYOFFTEMP (int16_t)180
//バッテリーヒーターオフの閾値
//30度(95)

//テスト用の値なので、適宜変えてください
//12/20本番仕様

//12/27さらに変更

#define HEATER_ON	1
#define HEATER_OFF	0

#define HEATER_ONEF 23
#define HEATER_OFFEF 14
#define HEATER_NTEF	111


int8_t HeaterEFTest;
short HeaterTest;//shortから変更
//ヒーターのオンオフ

void HeaterInit(void);
void controlBatteryTemp(void);

void ONHeater(void);
void OFFHeater(void);

void BHerrCheck();

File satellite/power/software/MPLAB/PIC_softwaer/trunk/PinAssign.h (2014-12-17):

#define H8KILL 		PIN_D0
#define ARKILL 		PIN_D1
#define RXLINE		PIN_C4
#define TXLINE		PIN_C5
#define CWLINE		PIN_D5
//電源ライン制御ピン

#define	CWKEY		PIN_C0
#define CWCLK		PIN_C1
#define CWDAT		PIN_C2
#define CWSTB		PIN_C3
//CW制御ピン

#define BATTERYHEATER PIN_D2
//BATTERYHEATER制御ピン



#define LSRECIEVE	PIN_D4
//生存信号受信ピン

#define ANTENNAEXPAND PIN_D3
//アンテナ展開ピン

#define BATLINE	PIN_D6
#define BATRST	PIN_D7
//充電回路リセット

//EMではアンテナ展開がPIND2に、ヒーターがPIND3にそれぞれついています。
//FMと回路図ではアンテナ展開がPIND3に、ヒーターがPIND2にそれぞれついています。

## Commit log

2013-12-28 Small fix for InvaderVM
    [InvaderVM.ino]
2013-12-29 Add LED Test
2014-12-17 rebuild as INVADER repository
    [MISSION_FM1.brd, MISSION_FM1.sch, OV_FPC.brd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]
2014-12-17 newly added
    [+X-ver3.12-1.idw, +X-ver3.12.ipt, -X-ver3.12.idw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]
2014-12-17 merged Invader3DViewer
    [invader_antennas.stl, invader_batteries.stl, invader_boards.stl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]
2014-12-17 added STL files
    [+X.stl, -X.stl, body.stl]
2014-12-17 merged INVADERxThree
    [invader_antennas.stl, invader_frame.stl, invader_pannel_mx.stl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]
2014-12-22 update EAGLE files
    [Comm_FM.brd, Comm_FM.sch, MAIN_FM.brd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]
2015-03-09 Update Morikawa HW files
    [MISSION_FM1.brd, MISSION_FM1.sch]
2015-03-24 update Morikawa HW files
    Rev:C
    [MISSION_FM1.brd, MISSION_FM1.sch]
2015-05-04 Updaetd Invader3DViewer
    [invader_antennas.stl, invader_batteries.stl, invader_boards.stl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]
2017-03-12 fix schematic bug and instruction manual
    MORIKAWA_FM: invert SMD LED direction.
    [MISSION_FM1.brd, MISSION_FM1.sch]
